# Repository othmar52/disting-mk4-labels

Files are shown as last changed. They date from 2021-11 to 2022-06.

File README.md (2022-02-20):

# disting-mk4-labels
Arduino based eurorack module displaying text on OLED displays  

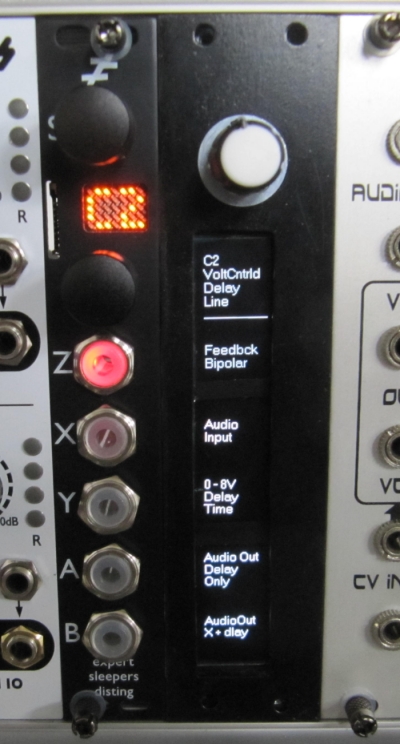
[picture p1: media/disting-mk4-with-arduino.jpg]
[](https://raw.githubusercontent.com/othmar52/disting-mk4-labels/main/media/disting-mk4-with-arduino.jpg?raw=true)
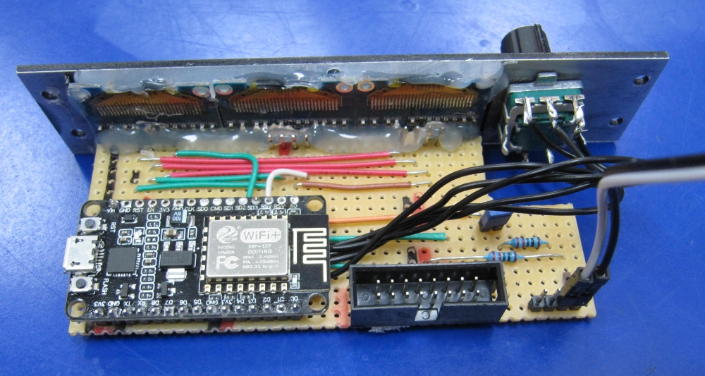
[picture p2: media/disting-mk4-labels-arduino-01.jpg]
[](https://raw.githubusercontent.com/othmar52/disting-mk4-labels/main/media/disting-mk4-labels-arduino-01.jpg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)
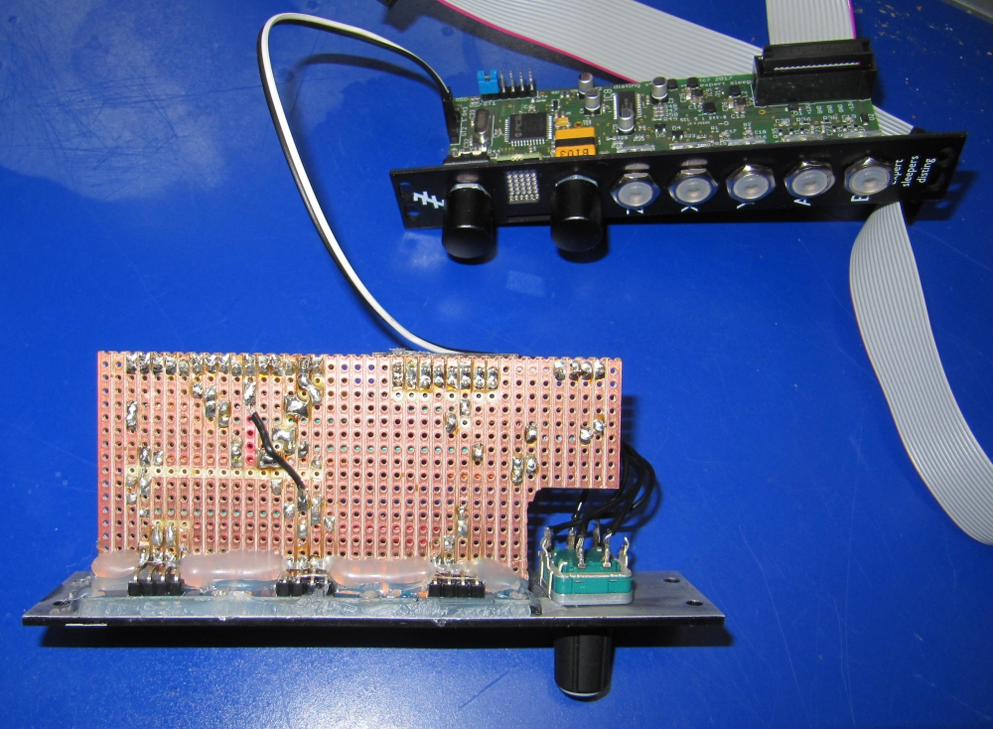
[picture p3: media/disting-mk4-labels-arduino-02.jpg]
[](https://raw.githubusercontent.com/othmar52/disting-mk4-labels/main/media/disting-mk4-labels-arduino-02.jpg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)
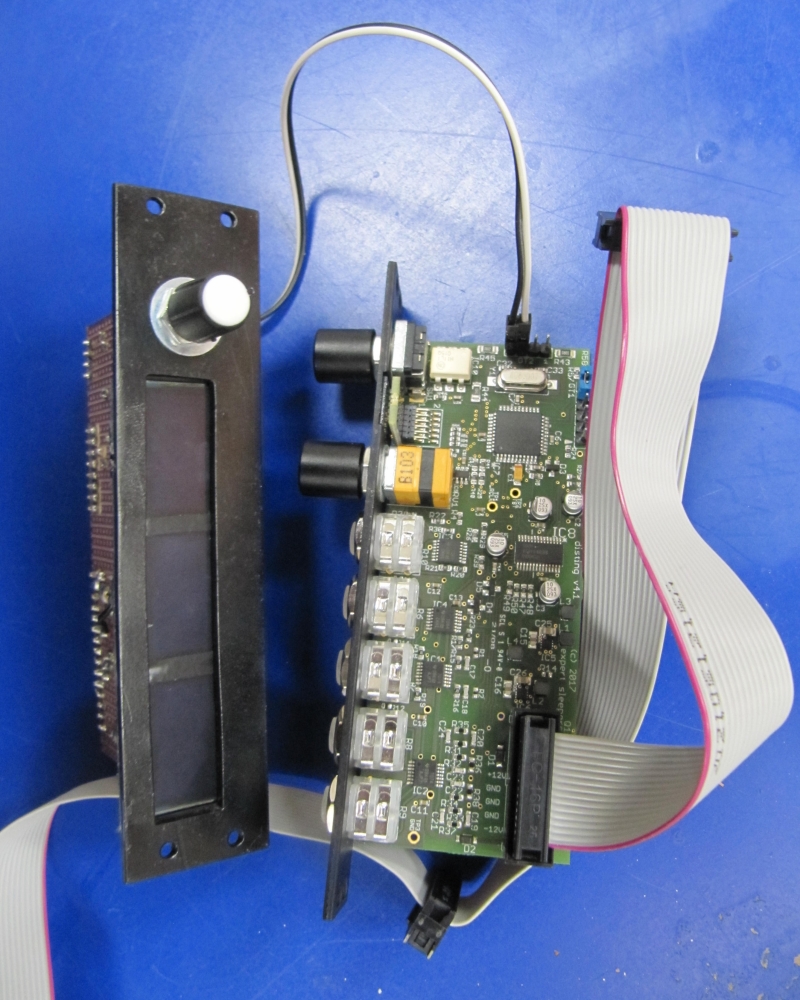
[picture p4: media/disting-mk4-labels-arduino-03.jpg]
[](https://raw.githubusercontent.com/othmar52/disting-mk4-labels/main/media/disting-mk4-labels-arduino-03.jpg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)

## Parts
-  [Expert Sleepers - disting mk4 Eurorack module](https://www.expert-sleepers.co.uk/downloads/manuals/disting_user_manual_4.20.pdf)
-  [NodeMCU](https://i2.wp.com/randomnerdtutorials.com/wp-content/uploads/2019/05/ESP8266-NodeMCU-kit-12-E-pinout-gpio-pin.png)
-  [3 x OLED Display 128 x 64](https://www.az-delivery.de/en/products/0-96zolldisplay)
-  [Rotary Encoder (Bourns Inc. PEC16-4015F-S0024)](https://www.digikey.at/product-detail/de/bourns-inc/PEC16-4015F-S0024/PEC16-4015F-S0024-ND/3780222)
-  2 x Resistor 10 K
-  2 x Resistor 220 Ohm

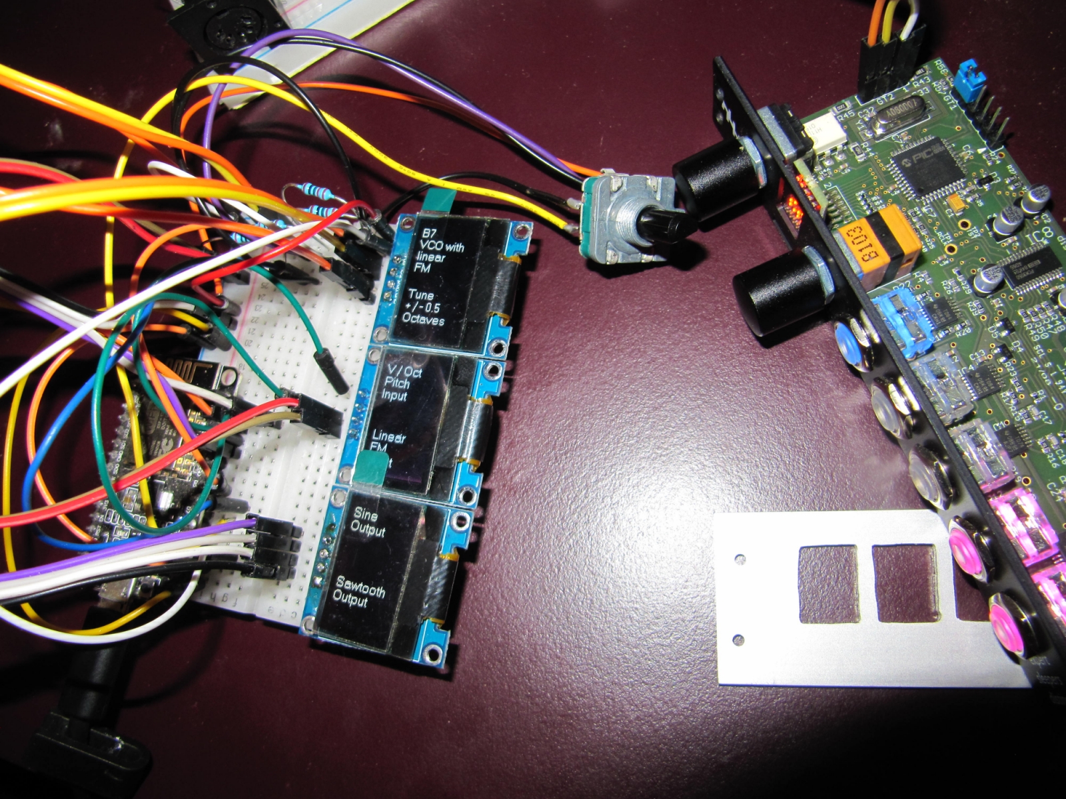
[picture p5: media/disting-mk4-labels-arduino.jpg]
Arduino for Expert Sleepers - disting mk4
  

## Schematics

```
         NodeMCU
   ┌──────────────────┐
   │◎ A0          D0 ◎│
   │◎ RSV         D1 ●│─────> all 3 OLED SCL
   │◎ RSV         D2 ●│─────> upper OLED SDA
   │◎ SD3         D3 ●│─────> center OLED SDA
   │◎ SD2         D4 ●│─────> lower OLED SDA
   │◎ SD1        3V3 ◎│
   │◎ CMD        GND ◎│ 
   │◎ SD0         D5 ●│─────> RotaryEncoder OUTA ──> (see below)
   │◎ CLK         D6 ●│─────> RotaryEncoder OUTB ──> (see below)
   │◎ GND         D7 ●│─────> RotaryEncoder SW
   │◎ 3V3         D8 ◎│
   │◎ EN          RX ◎│
   │◎ RST         TX ●│─────> Resistor 220 Ohm ──> Disting Midi Pin 3
   │◎ GND        GND ●│───┬─> all 3 OLED GND
 ┌─│● Vin        3V3 ●│─┐ ├─> RotaryEncoder GND (2x)
 │ └──────────────────┘ │ └─> Eurorack Power BUS GND
 │                      │ 
 │                      ├───> all 3 OLED VCC
 │                      ├───> Resistor 220 Ohm ──> Disting Midi Pin 4
 │                      ├───> Resistor 10K  ──> RotaryEncoder OUTA
 │                      └───> Resistor 10K  ──> RotaryEncoder OUTB
 │
 └──────────────────────────> to Eurorack power BUS 5V
```
```
                      OLED Screens
                   ┌────────────────┐
                   │ ╔═════════╗    │
                   │ ║  UPPER  ║    │
   NodeMCU D2  <───│●║ SDA     ║    │
   NodeMCU D1  <───│●║ SCL     ║    │
  NodeMCU 3V3  <───│●║ VCC     ║    │
  NodeMCU GND  <───│●║ GND     ║    │
                   │ ║         ║    │
                   │ ╚═════════╝    │
                   └────────────────┘
                   ┌────────────────┐
                   │ ╔═════════╗    │
                   │ ║  CENTER ║    │
   NodeMCU D3  <───│●║ SDA     ║    │
   NodeMCU D1  <───│●║ SCL     ║    │
  NodeMCU 3V3  <───│●║ VCC     ║    │
  NodeMCU GND  <───│●║ GND     ║    │
                   │ ║         ║    │
                   │ ╚═════════╝    │
                   └────────────────┘
                   ┌────────────────┐
                   │ ╔═════════╗    │
                   │ ║  LOWER  ║    │
   NodeMCU D4  <───│●║ SDA     ║    │
   NodeMCU D1  <───│●║ SCL     ║    │
  NodeMCU 3V3  <───│●║ VCC     ║    │
  NodeMCU GND  <───│●║ GND     ║    │
                   │ ║         ║    │
                   │ ╚═════════╝    │
                   └────────────────┘
```
```
Encoder (Bourns Inc. PEC16-4015F-S0024)

                 ┌─────────────────────┐
                 │                GND ●│─────> NodeMCU GND
                 │                     │
 NodeMCU GND <───│● GND                │
                 │       ENCODER       │
                 │         TOP   OUTB ●│──●──> NodeMCU D6
                 │        VIEW         │  │
  NodeMCU D7 <───│● SW                 │  └──> Resistor 10K ──> NodeMCU 3V3
                 │                     │
                 │               OUTA ●│──●──> NodeMCU D5
                 └─────────────────────┘  │
                                          └──> Resistor 10K ──> NodeMCU 3V3
```
```
Eurorack power busboard top view

     ╔═══╗
GATE ║◎ ◎║
  CV ║◎ ◎║
 +5V ║● ●║──> NodeMCU Vin
+12V ║◎ ◎╚╗
 GND ║◎ ◎╔╝
 GND ║● ●║──> NodeMCU GND
 GND ║◎ ◎║
-12V ║◎ ◎║ (red stripe)
     ╚═══╝
```
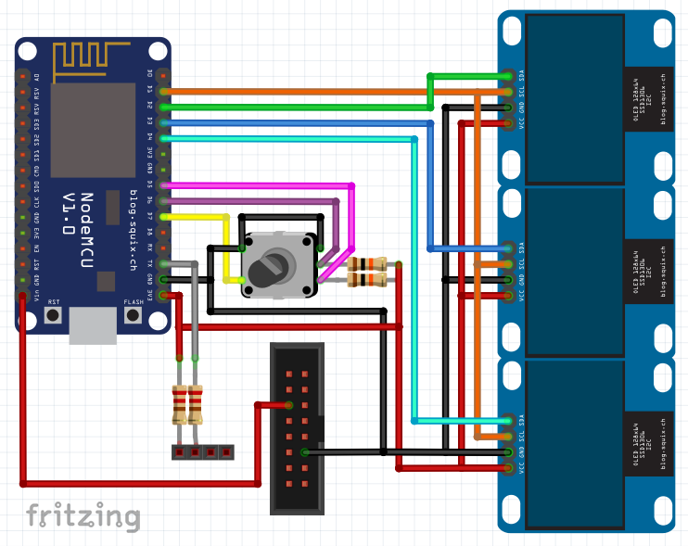
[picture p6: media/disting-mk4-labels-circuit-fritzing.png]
Arduino for Expert Sleepers - disting mk4
  

see my other [eurorack DIY projects](https://github.com/othmar52/eurorack)

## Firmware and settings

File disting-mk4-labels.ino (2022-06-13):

#include <Arduino.h>

#include <Wire.h>


#include <U8g2lib.h>

#define MAX_CHARS_PER_LINE 12

//U8G2_R0  No rotation, landscape
//U8G2_R1 90 degree clockwise rotation
//U8G2_R2 180 degree clockwise rotation
//U8G2_R3 270 degree clockwise rotation
U8G2_SSD1306_128X64_NONAME_1_SW_I2C scr1(U8G2_R1, /* clock=*/ D1, /* data=*/ D2, /* reset=*/ U8X8_PIN_NONE);   // All Boards without Reset of the Display
U8G2_SSD1306_128X64_NONAME_1_SW_I2C scr2(U8G2_R1, /* clock=*/ D1, /* data=*/ D3, /* reset=*/ U8X8_PIN_NONE);   // All Boards without Reset of the Display
U8G2_SSD1306_128X64_NONAME_1_SW_I2C scr3(U8G2_R1, /* clock=*/ D1, /* data=*/ D4, /* reset=*/ U8X8_PIN_NONE);   // All Boards without Reset of the Display

int lineHeigth = 14;

int currentPatchRequest = 0;
int currentRenderedPatchTitle = 1;
int currentRenderedPatch = 1;

unsigned long lastRenderedPatchTitle = 0;
unsigned long lastRenderedPatch = 0;

int renderPatchDelay = 1500;

int tolerance = 3;
String patchLetter = "";


bool welcome = true;

////////////////////////////////////////////////
// rotary encoder
// without interrupts because it seems to be not compatible with multiple oled stuff
//
// number of encoders
int numEnc = 1;
int encPinA[2] = {D5};
int encPinB[2] = {D6};
int lastModeA[2];
int lastModeB[2];
int curModeA[2];
int curModeB[2];
int encPos[2];
int encPosLast[2];
int change = 0;
int c = 0;
int debounceMilliseconds = 300;
unsigned long lastEncoderChange = 0;
////////////////////////////////////////////////



void setup(void) {
  setupEncoder();
  setupOledDisplays();
  
  setupMidiStuff();
  pinMode(D7, INPUT_PULLUP);
  
  drawScreen(scr1, 1, "4.22", "Disting", "MK4", "", "Arduino", "Labels", "Extension");
  //drawScreen(scr2, 2, "Expert", "Sleepers", "", "disting", "mk4", "");
  //drawScreen(scr3, 3, "firmware", "4.20", "", "", "", "");
}

byte stateButtuon = LOW;
void loop(void) {
  loopEncoder();
  loopPatchSelection();
  midiStuffLoop();

  // TODO: use push function of the encoder for really switching algorithm
  //if (digitalRead(D7) == HIGH) {
  //  Serial.println("button pressed");
  //}

  
}

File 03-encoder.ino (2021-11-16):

void decrementEncoder(int encoderIndex) {
  encPos[encoderIndex]--;
  if (encPos[encoderIndex] < 0) {
    encPos[encoderIndex] = numPatches * tolerance - 1;
  }
}

void incrementEncoder(int encoderIndex) {
  encPos[encoderIndex]++;
  if (encPos[encoderIndex] >= numPatches * tolerance) {
    encPos[encoderIndex] = 0;
  }
}



void setupEncoder() {
  // set up each encoder's values
  for (c = 0; c < numEnc; c++) {

    // set the pins form INPUT
    pinMode(encPinA[c], INPUT);
    pinMode(encPinB[c], INPUT);
    // set the modes and positions - on first read, it may change position once
    //   depending on how the encoders are sitting (having a HIGH position that
    //   gets compared to the initial LOW setting here in the first iteration of
    //   the loop).
    lastModeA[c] = LOW;
    lastModeB[c] = LOW;
    curModeA[c] = LOW;
    curModeB[c] = LOW;
    encPos[c] = 0;
    encPosLast[c] = 0;
  }
}

void loopEncoder () {
  // read in current values
  // set the change variable to 0.  If there is an encoder position change,
  //   this gets changed to 1.  This lets a later portion of the loop that
  //   a change has been made and it doesn't have to compare all the modes
  //   again.
  change = 0;
  // loop through each of the encoders
  for (c = 0; c < numEnc; c++) {
    // read the current state of the current encoder's pins
    curModeA[c] = digitalRead(encPinA[c]);
    curModeB[c] = digitalRead(encPinB[c]);
    // compare the four possible states to figure out what has happened
    //   then encrement/decrement the current encoder's position
    if (curModeA[c] != lastModeA[c]) {
      if (curModeA[c] == LOW) {
        if (curModeB[c] == LOW) {
          //encPos[c]--;
          decrementEncoder(c);
        } else {
          //encPos[c]++;
          incrementEncoder(c);
        }
      } else {
        if (curModeB[c] == LOW) {
          //encPos[c]++;
          incrementEncoder(c);
        } else {
          //encPos[c]--;
          decrementEncoder(c);
        }
      }
    }
    if (curModeB[c] != lastModeB[c]) {
      if (curModeB[c] == LOW) {
        if (curModeA[c] == LOW) {
          //encPos[c]++;
          incrementEncoder(c);
        } else {
          //encPos[c]--;
          decrementEncoder(c);
        }
      } else {
        if (curModeA[c] == LOW) {
          //encPos[c]--;
          decrementEncoder(c);
        } else {
          //encPos[c]++;
          incrementEncoder(c);
        }
      }
    }
    // set the current pin modes (HIGH/LOW) to be the last know pin modes
    //   for the next loop to compare to
    lastModeA[c] = curModeA[c];
    lastModeB[c] = curModeB[c];
    // if this encoder's position changed, flag the change variable so we
    //   know about it later
    if (encPos[c] != encPosLast[c]) {
      change = 1;
    }
  }

  if (change == 1 && millis() - lastEncoderChange > debounceMilliseconds) {
    lastEncoderChange = millis();
    // if an encoder has changed, do something with that information
    // here, I am just going to print all the encoder's positions
    //   if any of them change
    for (c = 0; c < numEnc; c++) {
      getCurrentPatchIndex();
      encPosLast[c] = encPos[c];
    }
    //Serial.println();
    // debounce - if there has been a change, wait for a bit (so to speak) to let the
    //   bounces settle - change to your liking
    //delay(200);
  }
}

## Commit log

2021-11-16 [INIT] adding current development status
    [disting-mk4-algorithms-v4.20.csv]
2021-11-18 [TASK] improve schematics in README
2021-11-22 [DOCUMENTATION] add fritzing circuit schematics
    [disting-mk4-labels.fzz]
2021-11-27 [TASK] improve text alignment on screens
    depending on line count a vertical offset gets applied.
    so the text lines will appear as centered as possible
    next to the physical disting mk4 jacks
    [disting-mk4-algorithms-v4.20.csv]
2021-11-27 [DOCUMENTATION] add image of powered module
2021-12-08 [TASK] add missing data of all firmware 4.20 algorithms
    [disting-mk4-algorithms-v4.20.csv]
2022-06-13 [CONTENT] added labels for firmware 4.22.1
    [disting-mk4-algorithms-v4.22.1.csv]
